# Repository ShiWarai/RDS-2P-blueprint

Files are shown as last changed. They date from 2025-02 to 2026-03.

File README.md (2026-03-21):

# RDS-2P-blueprint

Проект с чертежами малой робособаки для изготовления пластиковых деталей в стиле робота-панды. Техническое наименование: Robot Dog Small - 2 Plastic (RDS-2P)

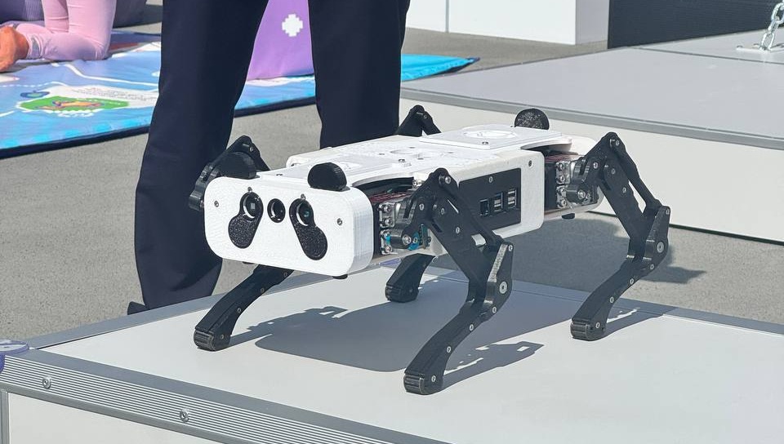
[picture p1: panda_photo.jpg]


## Состав репозитория

- `корпус/` - детали корпуса и связанные сборки.
- `ноги/` - сборки ног и вспомогательные элементы.
- `зарядная станция/` - чертежи зарядной станции.
- `переменные/` - параметрические конфигурации и общие размеры.
- `мет. изделия/` - стандартные и покупные металлические элементы.
- `электроника/` - посадочные и связанные элементы электроники.
- `export/` - экспортные материалы для печати и прочие материалы.

## Требуемое ПО

- T-Flex CAD: 17.1.36.0

## Компоненты

Список компонентов доступен в файле `компоненты.xlsx` в корне репозитория.

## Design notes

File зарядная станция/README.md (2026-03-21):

# RDS-2P-blueprint - зарядная станция

Чертежи док-станция (она же DOG station) для зарядки аккумуляторов и робота от брюшных контактов.
Требует подключения от линии переменного тока 220 вольт.



Версия T-Flex CAD: 17.1.33.0

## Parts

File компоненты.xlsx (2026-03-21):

Наименование | Кол-во | Описание | Ссылка | Цена | Подытог
Микрокомпьютер Orange Pi 5 Pro | 1 |  | https://aliexpress.ru/item/1005006832687928.html | 16755 | 16755.0₽
Радиатор для электроники, 10 штук | 1 |  | https://www.ozon.ru/product/10-shtuk-radiator-11h11h5mm-633950693 | 403 | 403.0₽
Сервопривод Feetech SCS40 7.4v | 12 | Лучше с запасом пару штук ещё, кроме этого кол-ва купить. Также можно заказать более дешево на Aliexpress | https://aliexpress.ru/item/1005001732588093.html?sku_id=12000021600748435 | 7579 | 90948.0₽
Аккумулятор 21700 | 6 |  | https://www.ozon.ru/product/ao-energiya-akkumulyatornaya-batareyka-21700-3-6-v-4500-mach-1-sht-742439310/ | 336 | 2016.0₽
BMS 2S 20A плата защиты с балансировкой | 2 | С одной из них нужно будет перенести мосфеты на другую | https://www.ozon.ru/product/bms-2s-20a-plata-zashchity-s-balansirovkoy-8-4-v-dlya-sborok-akkumulyatorov-1162983848/ | 251 | 502.0₽
Кнопка антивандальная | 1 |  | https://www.ozon.ru/product/antivandalnaya-knopka-s-fiksatsiey-1120847177/ | 406 | 406.0₽
Вентилятор 5В 50x50x10 | 1 |  | https://www.ozon.ru/product/kuler-50-50-10-5v-0-2a-2pin-provod-25sm-ventilyator-ohlazhdeniya-1197519312 | 308 | 308.0₽
Понижающий преобразователь LM2596S | 1 |  | https://www.ozon.ru/product/ponizhayushchiy-preobrazovatel-napryazheniya-dc-dc-gsmin-lm2596s-siniy-285604795 | 185 | 185.0₽
Гнездо питания DC-022, 5.5x2.1 | 1 |  | Гнездо питания 5.5x2.5, DC-022В с заглушкой. 1 штука купить на OZON по низкой цене (1701259441) (https://www.ozon.ru/product/gnezdo-pitaniya-5-5x2-5-dc-022v-s-zaglushkoy-1-shtuka-1701259441/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) | 171 | 171.0₽
Индикатор заряда аккумулятора | 1 |  | https://www.ozon.ru/product/indikator-zaryada-napryazheniya-emkosti-batarei-18650-ot-1s-do-8s-siniy-1802287993 | 266 | 266.0₽
Рычаг-качалка 25т для сервопривода | 12 |  | https://www.ozon.ru/product/metallicheskiy-povorotnyy-rychag-servoprivoda-usilennyy-vintami-25t-1637096571 | 150 | 1800.0₽
Гайки вплавляемые, M3x5x4.2, 250 штук | 1 |  | https://aliexpress.ru/item/1005004629314742.html?sku_id=12000029896431130 | 504 | 504.0₽
Провода 24AWG (чёрные) | 1 | От 5 метров |  | 260 | 260.0₽
Провода 24AWG (красный) | 1 | От 5 метров |  | 260 | 260.0₽
Провода 24AWG (фиолетовый) | 1 | От 5 метров |  | 260 | 260.0₽
Провода 12AWG (чёрный) | 1 | От 1 метра | https://www.ozon.ru/product/provod-12awg-3-33-mm2-v-silikonovoy-izolyatsii-luzhenaya-med-1-metr-chernyy-1-metr-krasnyy-1514151393 | 228 | 228.0₽
Провода 12AWG (красный) | 1 | От 1 метра | https://www.ozon.ru/product/provod-12awg-3-33-mm2-v-silikonovoy-izolyatsii-luzhenaya-med-1-metr-chernyy-1-metr-krasnyy-1514151393 | 228 | 228.0₽
Макетная плата | 2 |  | https://www.ozon.ru/product/maketnaya-plata-100x100-303022593 | 195 | 390.0₽
Провода Arduino, набор, 30 штук | 2 |  | https://www.ozon.ru/product/provoda-peremychki-dupont-dlya-radiokonstruktora-10sm-nabor-3h10shtuk-dlya-arduino-raspberry-pi-1582137925 | 185 | 370.0₽
Штыревые однорядные разъемы, 10 штук | 1 |  | https://www.ozon.ru/product/shtyrevye-odnoryadnye-razemy-na-platu-papa-pls-40-pryamye-40-pin-2-54-mm-10-shtuk-pld-razem-1046480730/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 | 338 | 338.0₽
Разъёмы XT30U, набор, 10 шт | 3 |  | https://www.ozon.ru/product/konnektor-silovoy-xt30u-m-f-razem-papa-mama-5-par-amass-1410077690 | 424 | 1272.0₽
Штекеры JST SM2.54, мама-папа | 1 |  | https://www.ozon.ru/product/shteker-razem-razemy-dlya-provodov-konnektor-dlya-provodov-jst-sm2-54-sm-2p-sm-2r-papa-mama-10-par-1545309946/ | 394 | 394.0₽
Термоусадка, набор | 1 | Нужна для изоляции провода и является опицональной | https://www.ozon.ru/product/nabor-termousadochnyh-trubok-800-shtuk-v-korobke-termousadka-1196462435 | 467 | 467.0₽
Подшипники | 1 | Сложно пока точка сказать, состав часто меняется. В основном подшипники с 6ШПЗ |  | 3000 | 3000.0₽
Датчик положения MPU 9250 | 1 |  | https://www.ozon.ru/product/modul-mpu-9250-mpu9250-giroskop-akselerometr-magnitometr-1003900958 | 934 | 934.0₽
Пластик PLA, черный, 1 кг | 2 | Для печати можно выбрать любой пластик, без разницы | https://www.ozon.ru/product/katushka-pla-plastika-esun-1-75-mm-1kg-chernaya-306558060 | 1845 | 3690.0₽
Пластик PLA, белый, 1 кг | 2 |  | https://www.ozon.ru/product/pla-plastik-dlya-3d-printera-filament-pla-esun-1-75-mm-1kg-holodno-belaya-306557816 | 1849 | 3698.0₽
Пластик TPU 75A, 500 грамм | 1 | Мягкий пластик для лапок | https://www.ozon.ru/product/tpu-plastik-dlya-3d-printera-standard-black-1-75-mm-0-5-kg-eryone-chernyy-1035822099 | 1962 | 1962.0₽
Плата управления двигателями TTL | 1 |  | https://aliexpress.ru/item/1005002425419341.html?sku_id=12000021278492429 | 784 | 784.0₽
Камера Orbbec Astra Pro | 1 | Опционально! | https://aliexpress.ru/item/1005004866712306.html?sku_id=12000030809838677 | 5193
Капсуль микрофона | 1 |  |  | 120
AUX разъем | 1 |  | https://www.ozon.ru/product/razem-audio-jack-stereo-shteker-jack-3-5-mm-4-kontakta-metallicheskiy-korpus-na-kabel-pod-1277486516/ | 207
Динамик 2W | 1 |  |  | 200
Усилитель звука 2W | 1 |  | https://www.ozon.ru/product/usilitel-zvuka-d-klassa-na-mikrosheme-pam8302-1664428311/ | 251
 |  |  |  | Итог: | 132799.0₽

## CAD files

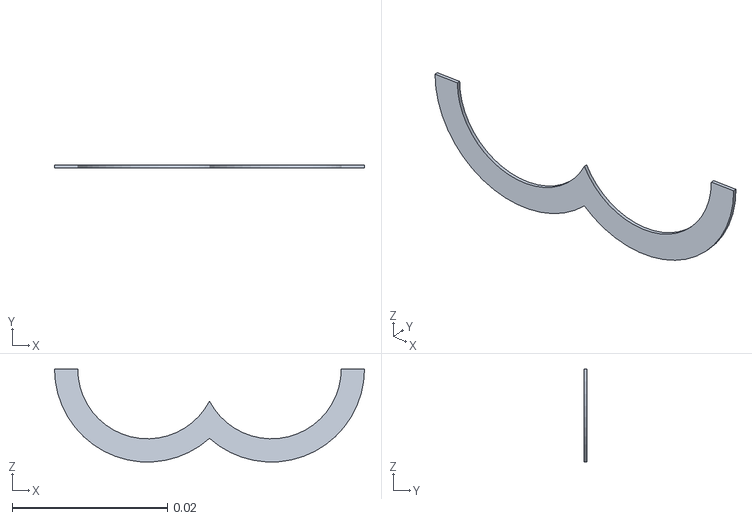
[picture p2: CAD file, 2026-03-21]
прочее/улыбка.obj
0.04 x 0.000399 x 0.012

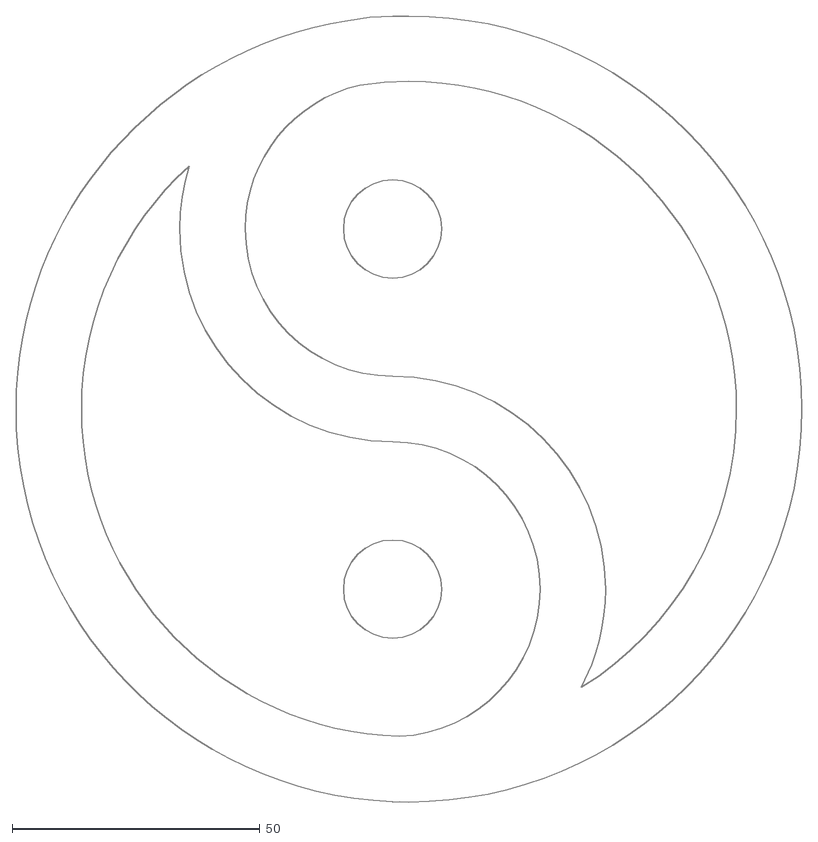
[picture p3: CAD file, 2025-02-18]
прочее/инь-янь.dxf
158.7 x 158.8

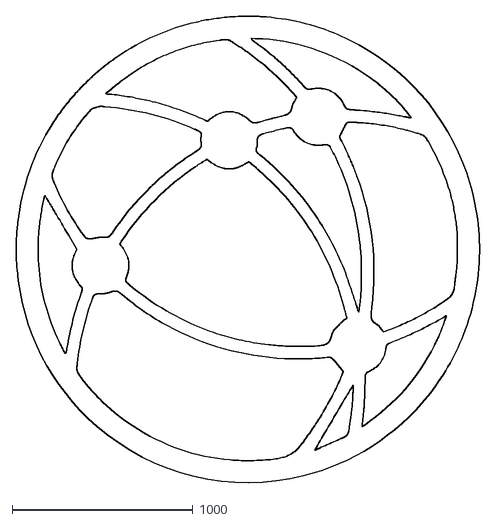
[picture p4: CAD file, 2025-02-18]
прочее/ИИТ.dxf
2561.9 x 2578.8

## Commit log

2025-02-18 Build: перенос репозитория из GitLab
    [ИИТ.dxf, инь-янь.dxf]
2025-02-18 Feat: добавлен дисплей для отображения эмоций робота
    [улыбка.obj]
2025-02-19 Fix: увеличены отступы после проверки
2025-02-26 Fix: исправлены отверстия для винтов спереди камеры
2025-02-27 Feat: добавлен держатель для дисплея
2025-03-01 Fix: добавлено пространство для компонентов на тыльной стороне экрана
2025-03-12 Feat: добавлена решётка
2025-03-14 Fix: изменена плотность и положение сетки
2025-04-25 Feat: добавлен новый переходник к LTE модулю
    Также сместил динамик в бок
2025-06-16 Fix: доработка после печати
2025-06-16 Build: добавлены файлы зарядной станции
2025-06-20 Feat: добавлен калибровочный фиксатор
2025-06-21 Fix: добавлена толщина и ручка для фиксатора
2025-06-21 Fix: доработан фиксатор
2025-07-04 Build: обновил сборку для оптимизации
2025-07-04 Fix: обновлён .gitignore
2025-07-14 Fix: оптимизации сборки
2025-07-14 Docs: добавлена анимация сборки и разборки
2025-10-03 Test: добавил спейсер для замены множества подшипников
2025-10-04 Fix: добавлен спейсер в сборку
2025-10-22 Feat: увеличена толщина голени
2025-10-22 Fix: ещё толще сделал голень робота
2025-11-29 Feat: добавлен оптический датчик
2026-03-16 Build: обновил версию T-Flex CAD, изображение и исправил ошибки
2026-03-16 Feat: добавил несколько анимацией разборок и старую таблицу компонентов
    [компоненты.xlsx]
